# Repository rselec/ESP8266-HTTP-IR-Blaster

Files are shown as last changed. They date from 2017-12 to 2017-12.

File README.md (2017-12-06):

# IR-Gateway

Ethernet (WiFi) to IR-Code Gateway to connect normal HiFi devices to the IoT.
Firmware is a fork of https://github.com/mdhiggins/ESP8266-HTTP-IR-Blaster and modified for a special Hardware.

Versions:
0.1 - development prototype on breadboard
0.2 - flying prototype with construction parts, transmitter only, longtime-test passed
0.3 - with custom back pcb and 3D case, wip

Kurze Übersicht der wichtigen Git-Befehle/Workflow:

1. bevor gearbeitet wird, Arbeitskopie aktualisieren:
	git pull
	
2. am Projekt arbeiten, nicht zu viel auf einmal
	
3. Änderungen überprüfen:
	git status
	
4. alle Änderungen zum Index hinzufügen:
	git add *
	
5. anschließend Änderungen im Index einchecken, mit kurzer Beschreibung:
	git commit -m "Commit-Nachricht"
	
6. jetzt noch die Änderungen zu bitbucket hochladen:
	git push

Release Versionen benennen (Tagging):

1. Versionsnummer in der main.c ändern (Schema "1.0")

2. compilieren und einen commit erstellen (wie oben)

3. den commit taggen: git tag -a v1.0 -m "release of version 1.0"

4. git push und git push --tags ausführen um den Tag auf den Server zu schieben

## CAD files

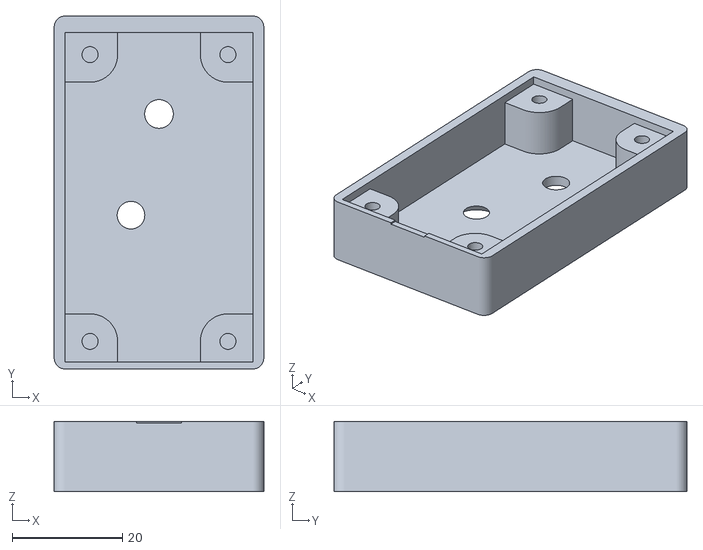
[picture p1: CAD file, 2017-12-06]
3D/STL/ir_gateway_case_03_front.stl
38.0 x 64.0 x 12.8

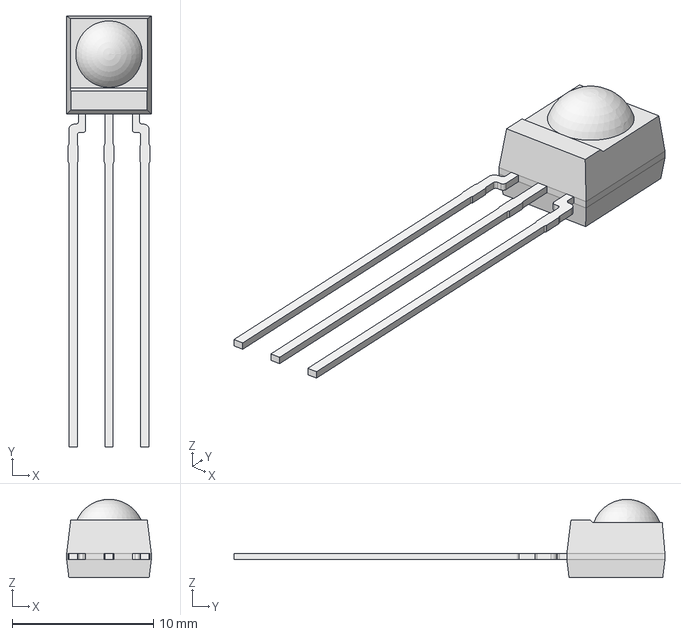
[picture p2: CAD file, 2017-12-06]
3D/TSOP483X.stp
6.00 x 30.5 x 5.55 mm
GO-100184
GO-100184.04

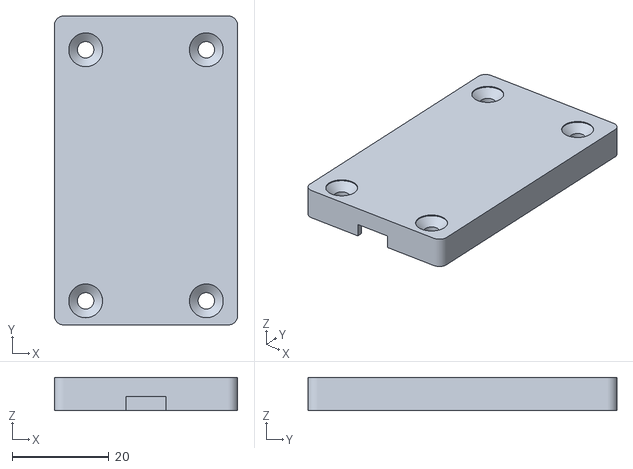
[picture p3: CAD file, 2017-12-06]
3D/STL/ir_gateway_case_03_back.stl
38.0 x 64.0 x 6.90

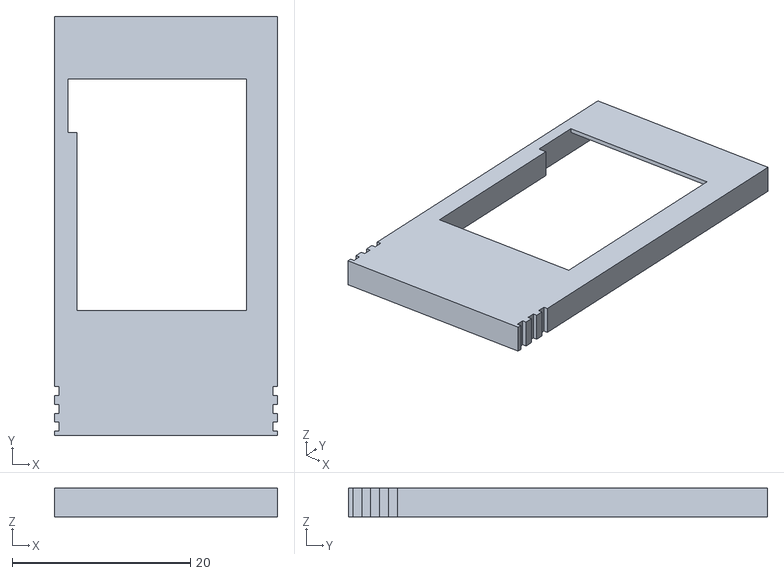
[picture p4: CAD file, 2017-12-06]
3D/STL/ir_gateway_case_03_spacer.stl
25.0 x 47.0 x 3.20

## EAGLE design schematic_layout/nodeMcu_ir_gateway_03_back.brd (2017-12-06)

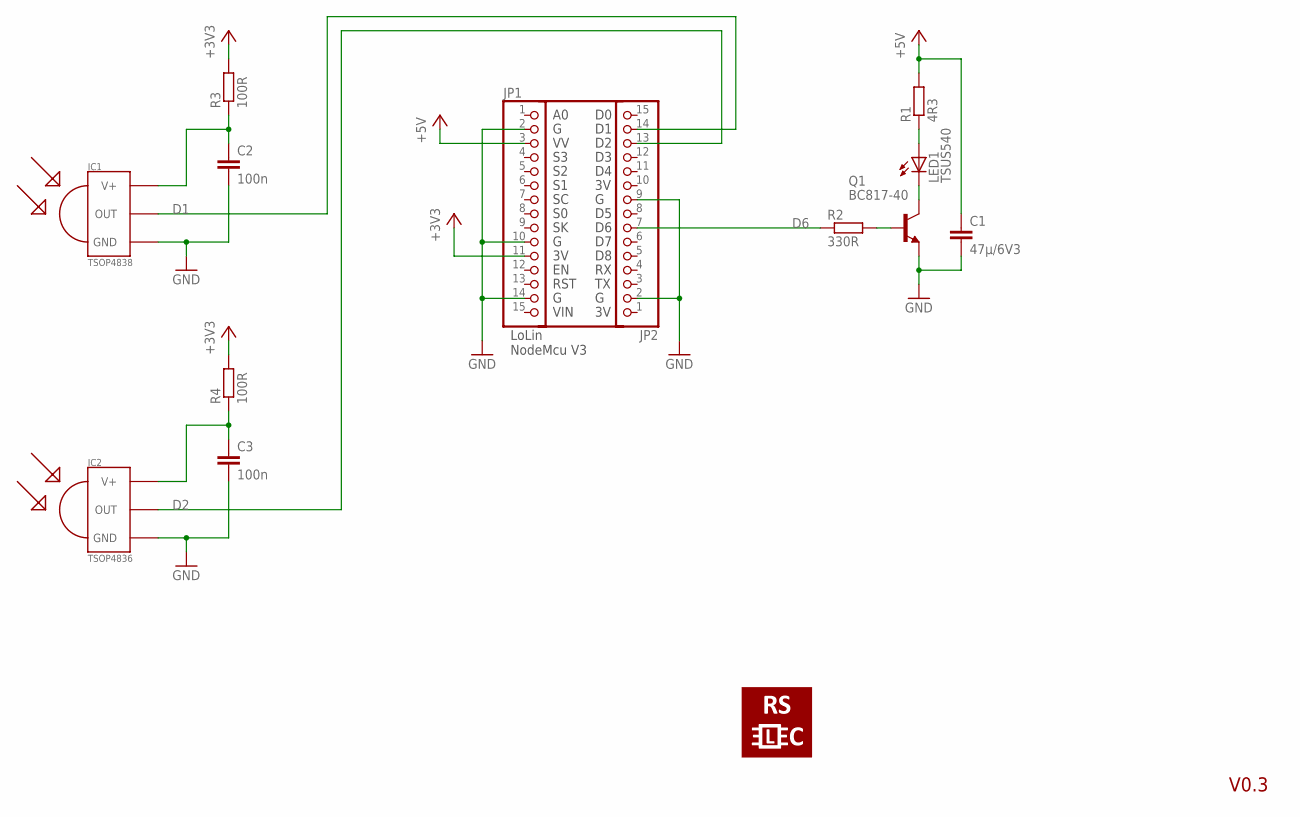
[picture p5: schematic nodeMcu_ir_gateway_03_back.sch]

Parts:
C1: 47µ/6V3; C1206
C2, C3: 100n; C0805
IC1: TSOP4838; TSOP18XX_H
IC2: TSOP4836; TSOP18XX_H
JP1, JP2: PINHD-1X15_2.54; 1X15
LED1: TSUS540; LED5MM
LOGO1: LOGO400N; LOGO_400N
Q1: BC817-40; SOT23-BEC
R1: 4R3; 0207/10
R2: 330R; R0805
R3, R4: 100R; R0805

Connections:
+3V3: JP1.11, R3.2, R4.2
+5V: C1.1, JP1.3, R1.2
D1: IC1.OUT, JP2.14
D2: IC2.OUT, JP2.13
D6: JP2.7, R2.1
GND: C1.2, C2.2, C3.2, IC1.GND, IC2.GND, JP1.2, JP1.10, JP1.14, JP2.2, JP2.9, Q1.E
unnamed: Q1.B, R2.2
unnamed: LED1.K (C), Q1.C
unnamed: LED1.A, R1.1
unnamed: C2.1, IC1.VCC (V+), R3.1
unnamed: C3.1, IC2.VCC (V+), R4.1

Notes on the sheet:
RST
VIN
LoLin NodeMcu V3
V0.3

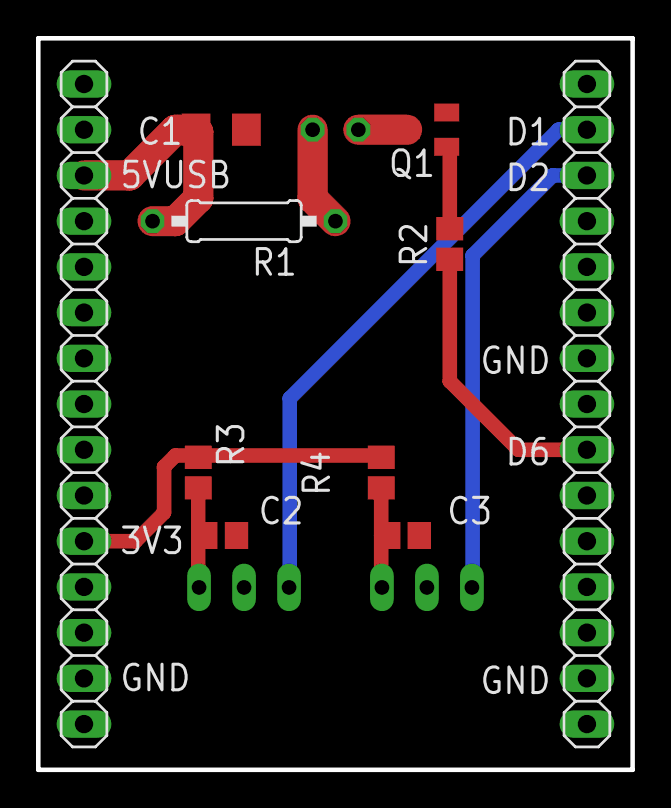
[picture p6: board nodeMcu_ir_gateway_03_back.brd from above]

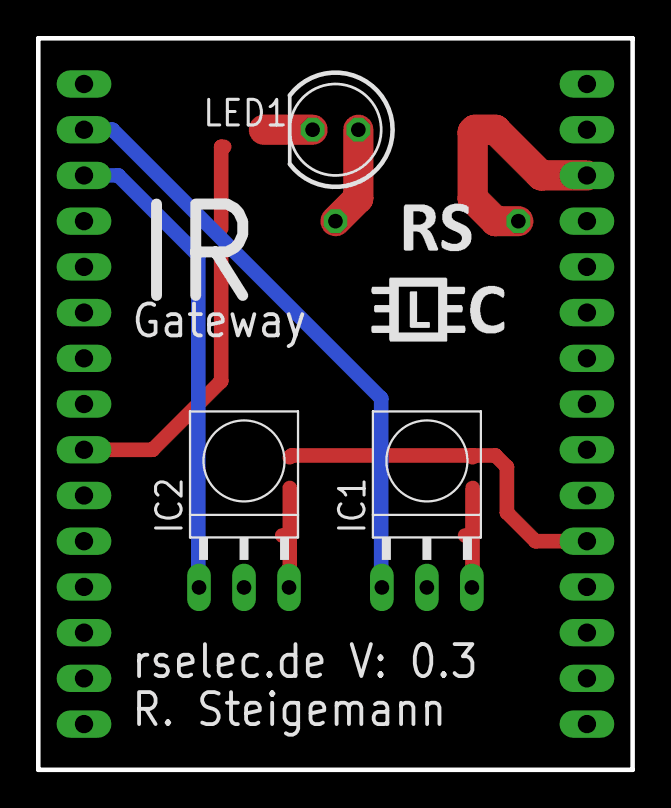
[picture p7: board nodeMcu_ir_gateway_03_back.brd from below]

Board: 2 copper layers, 33.0 x 40.6 mm, 14 parts (4 on the bottom side), 11 nets.

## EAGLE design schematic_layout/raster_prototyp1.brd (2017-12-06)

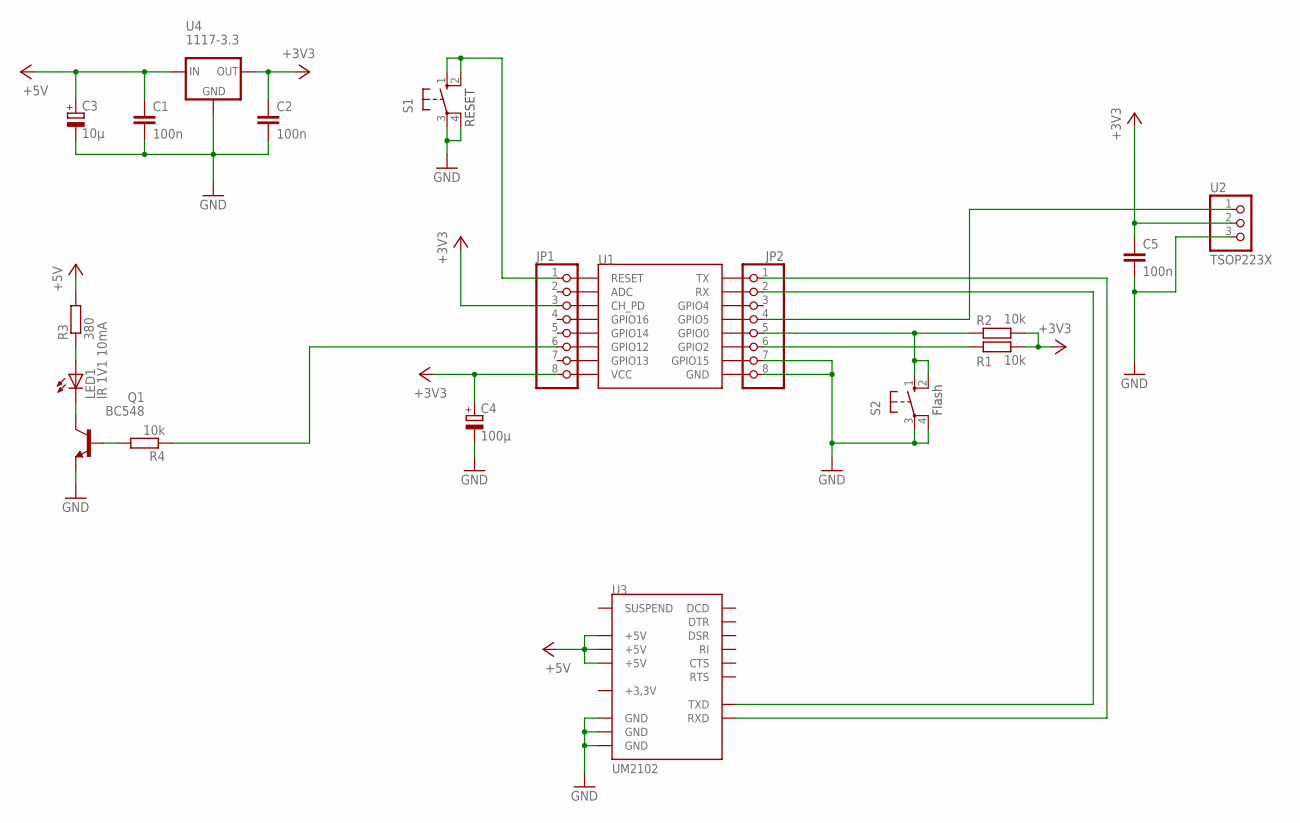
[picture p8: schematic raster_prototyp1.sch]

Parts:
C1, C2, C5: 100n; C0805
C3: 10µ; E2,5-5
C4: 100µ; E2,5-7
JP1, JP2: PINHD-1X8_2.54; 1X08
LED1: IR 1V1 10mA; LED5MM
Q1: BC548; TO92-EBC
R1, R2, R4: 10k; 0207/10
R3: 380; 0207/15
S1, S2: 10-XX; B3F-10XX
U1: ESP12SMD; ESP12-SMD
U2: TSOP223X; 1X03
U3: UM2102
U4: 1117-3.3; SOT223

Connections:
+3,3V: U3.ST2-11 (+3,3V)
+3V3: C2.1, C4.+, C5.1, JP1.3, JP1.8, R1.2, R2.2, U2.2, U4.2 (OUT)
+5V: C1.1, C3.+, R3.2, U3.ST1-3 (+5V), U3.ST2-9 (+5V), U3.ST3-7 (+5V), U4.3 (IN)
GND: C1.2, C2.2, C3.-, C4.-, C5.2, JP2.7, JP2.8, Q1.E, S1.3, S1.4 (P1), S2.3, S2.4 (P1), U2.3, U3.ST1-1 (GND), U3.ST2-7 (GND), U3.ST3-9 (GND), U4.1 (GND)
unnamed: JP2.4, U2.1
unnamed: JP2.6, R1.1
unnamed: LED1.A, R3.1
unnamed: JP1.1, S1.1 (S), S1.2 (S1)
unnamed: LED1.K (C), Q1.C
unnamed: JP2.5, R2.1, S2.1 (S), S2.2 (S1)
unnamed: Q1.B, R4.2
unnamed: JP1.6, R4.1
unnamed: JP2.1, U3.ST2-5 (RXD)
unnamed: JP2.2, U3.ST2-3 (TXD)

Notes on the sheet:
RESET
Flash

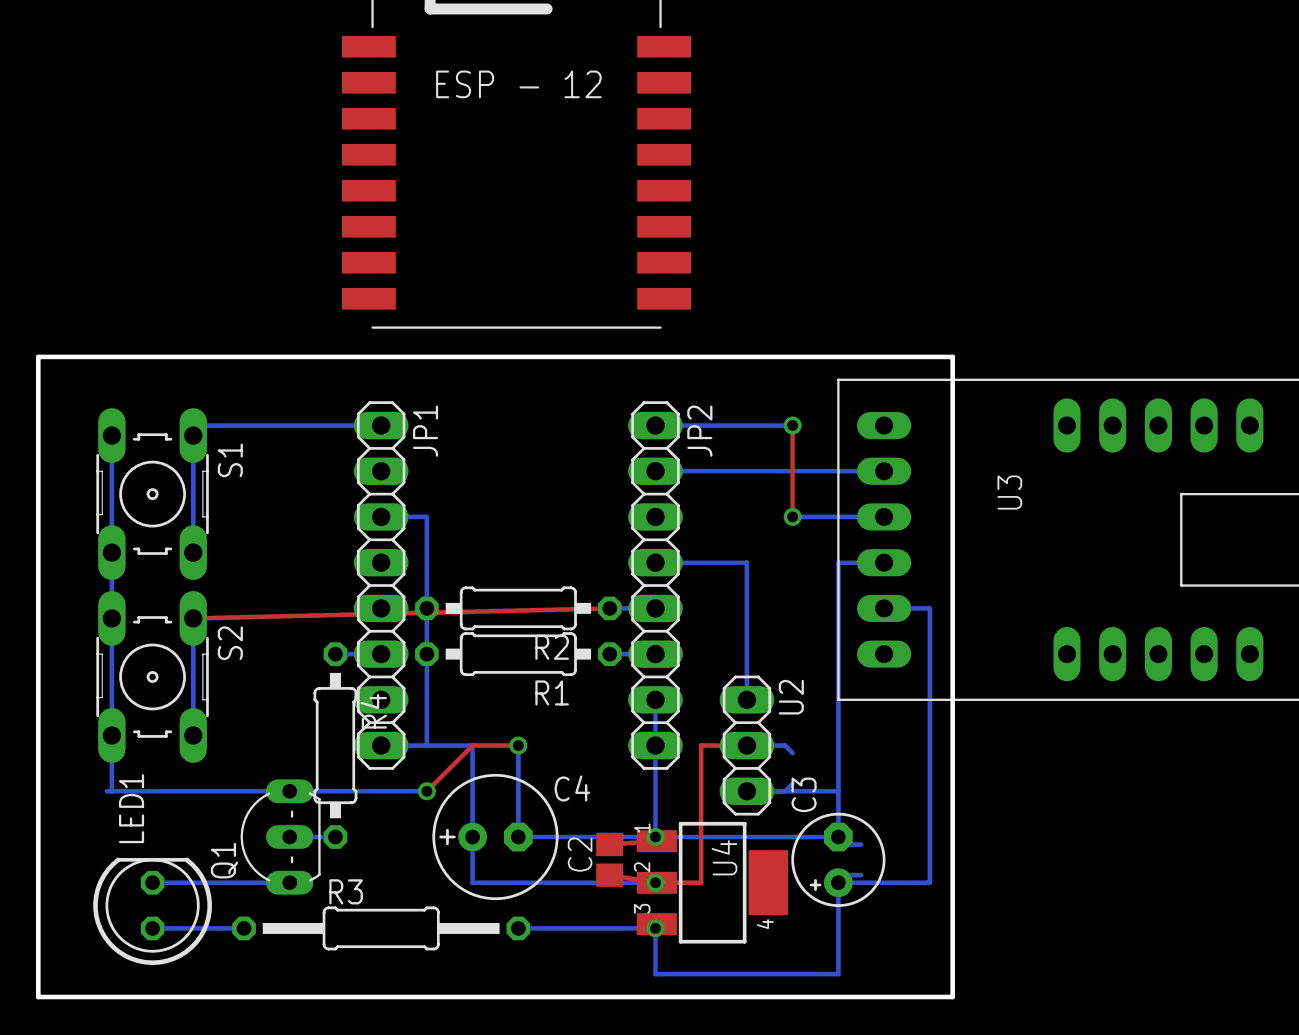
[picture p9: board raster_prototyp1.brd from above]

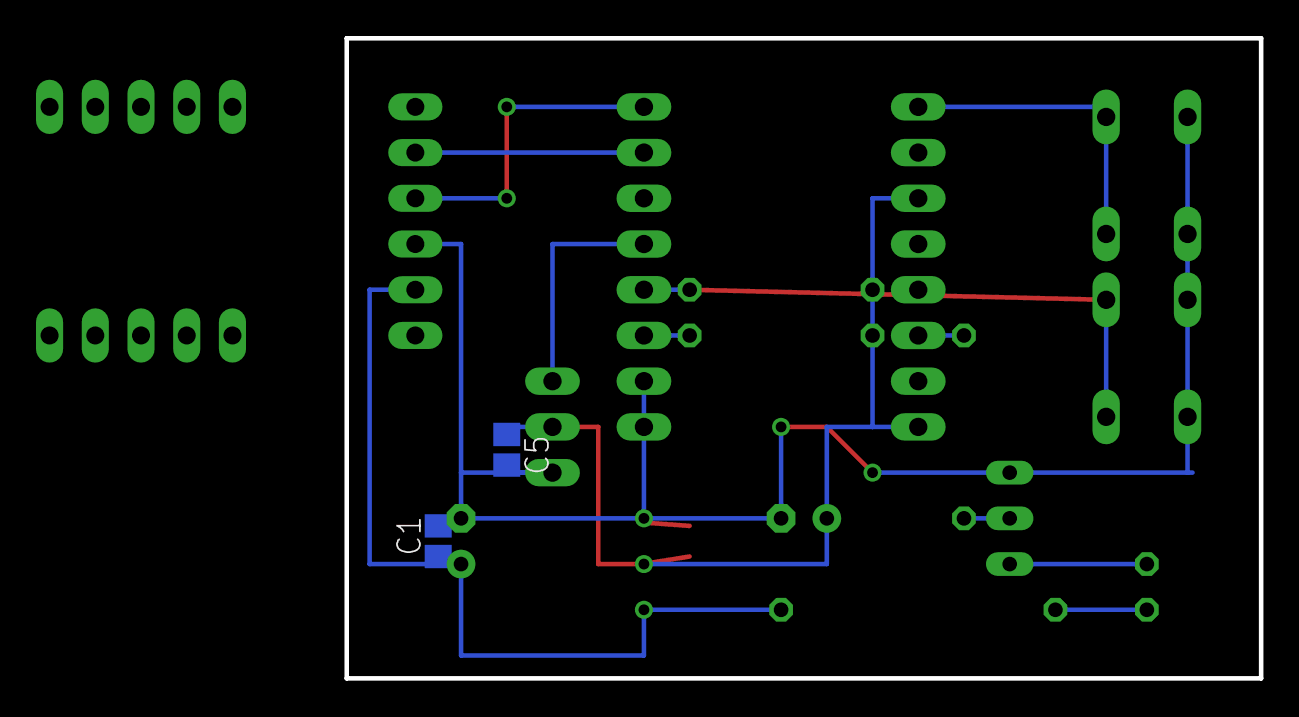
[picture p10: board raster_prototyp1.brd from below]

Board: 2 copper layers, 50.8 x 35.6 mm, 19 parts (2 on the bottom side), 13 nets.

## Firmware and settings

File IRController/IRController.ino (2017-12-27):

#include <FS.h>                                               // This needs to be first, or it all crashes and burns

#include <IRremoteESP8266.h>
#include <IRsend.h>
#include <IRrecv.h>
#include <IRutils.h>
#include <ESP8266WiFi.h>
#include <WiFiManager.h>                                      // https://github.com/tzapu/WiFiManager WiFi Configuration Magic
#include <ESP8266mDNS.h>                                      // Useful to access to ESP by hostname.local

#include <ArduinoJson.h>
#include <ESP8266WebServer.h>
#include <ESP8266HTTPClient.h>
#include <ArduinoOTA.h>
#include "sha256.h"

#include <Ticker.h>                                           // For LED status
#include <NTPClient.h>

// User settings are below here

const bool getExternalIP = false;                             // Set to false to disable querying external IP

const bool getTime = true;                                    // Set to false to disable querying for the time
const int timeOffset = +3600;                                // Timezone offset in seconds

int pinr1 = D1;                                               // Receiving pin
int pins1 = D6;                                               // Transmitting preset 1
//int pins2 = 5;                                                // Transmitting preset 2
//int pins3 = 12;                                               // Transmitting preset 3
//int pins4 = 13;                                               // Transmitting preset 4

// User settings are above here

const int configpin = 0;                                      // GPIO0 = flash key
const int ledpin = BUILTIN_LED;                               // Built in LED defined for WEMOS people
const char *wifi_config_name = "IR-Gateway Configuration";
const char serverName[] = "checkip.dyndns.org";
int port = 80;
char passcode[20] = "";
char host_name[20] = "";
char port_str[6] = "80";
char user_id[60] = "";
const char* fingerprint = "8D 83 C3 5F 0A 09 84 AE B0 64 39 23 8F 05 9E 4D 5E 08 60 06";

char static_ip[16] = "192.168.250.250";
char static_gw[16] = "192.168.250.1";
char static_sn[16] = "255.255.255.0";

DynamicJsonBuffer jsonBuffer;
JsonObject& deviceState = jsonBuffer.createObject();

ESP8266WebServer server(port);
HTTPClient http;
Ticker ticker;

bool shouldSaveConfig = false;                                // Flag for saving data
bool holdReceive = false;                                     // Flag to prevent IR receiving while transmitting

IRrecv irrecv(pinr1);
IRsend irsend1(pins1);
//IRsend irsend2(pins2);
//IRsend irsend3(pins3);
//IRsend irsend4(pins4);

const unsigned long resetfrequency = 259200000;                // 72 hours in milliseconds
const char* poolServerName = "time.nist.gov";

WiFiUDP ntpUDP;
NTPClient timeClient(ntpUDP, poolServerName, timeOffset, 3600000);

char _ip[16] = "";

unsigned long lastupdate = 0;

class Code {
  public:
    char encoding[14] = "";
    char address[20] = "";
    char command[40] = "";
    char data[40] = "";
    String raw = "";
    int bits = 0;
    char timestamp[40] = "";
    bool valid = false;
};

Code last_recv;
Code last_recv_2;
Code last_recv_3;
Code last_recv_4;
Code last_recv_5;
Code last_send;
Code last_send_2;
Code last_send_3;
Code last_send_4;
Code last_send_5;


//+=============================================================================
// Callback notifying us of the need to save config
//
void saveConfigCallback () {
  Serial.println("Should save config");
  shouldSaveConfig = true;
}


//+=============================================================================
// Reenable IR receiving
//
void resetReceive() {
  if (holdReceive) {
    Serial.println("Reenabling receiving");
    irrecv.resume();
    holdReceive = false;
  }
}


//+=============================================================================
// Valid command request using HMAC
//
bool validateHMAC(String epid, String mid, String timestamp, String signature) {
    if (!String(user_id).startsWith("amzn1.account.")) {
      Serial.println("Warning, user_id appears to be in the wrong format, security check will most likely fail. Should start with amzn1.account.***");
    }

    time_t timethen = timestamp.toInt();
    time_t timenow = timeClient.getEpochTime() - timeOffset;

    if (abs(timethen - timenow) > 30) {
      Serial.println("Failed security check, signature is too old");
      Serial.print("Server: ");
      Serial.println(timethen);
      Serial.print("Local: ");
      Serial.println(timenow);
      Serial.print("MID: ");
      Serial.println(mid);
      return false;
    }

    uint8_t *hash;
    String key = String(user_id);
    Sha256.initHmac((uint8_t*)key.c_str(), key.length()); // key, and length of key in bytes
    Sha256.print(epid);
    Sha256.print(mid);
    Sha256.print(timestamp);
    hash = Sha256.resultHmac();
    String computedSignature = bin2hex(hash, HASH_LENGTH);

    if (computedSignature != signature) {
      Serial.println("Failed security check, signatures do not match");
      Serial.print("1: ");
      Serial.println(signature);
      Serial.print("2: ");
      Serial.println(computedSignature);
      Serial.print("MID: ");
      Serial.println(mid);
      return false;
    }

    Serial.println("Passed security check");
    Serial.print("MID: ");
    Serial.println(mid);
    return true;
}


//+=============================================================================
// Get User_ID from Amazon Token (memory intensive and causes crashing)
//
String getUserID(String token)
{
  http.setTimeout(5000);
  String url = "https://api.amazon.com/user/profile?access_token=";
  String uid = "";
  http.begin(url + token, fingerprint);
  int httpCode = http.GET();
  String payload = http.getString();
  Serial.println(url + token);
  Serial.println(httpCode);
  Serial.println(payload);
  if (httpCode > 0 && httpCode == HTTP_CODE_OK) {
    DynamicJsonBuffer jsonBuffer;
    JsonObject& json = jsonBuffer.parseObject(payload);
    uid = json["user_id"].as<String>();
  } else {
    Serial.println("Error retrieving user_id");
    payload = "";
  }
  http.end();
  return uid;
}


//+=============================================================================
// Toggle state
//
void tick()
{
  int state = digitalRead(ledpin);  // get the current state of GPIO1 pin
  digitalWrite(ledpin, !state);     // set pin to the opposite state
}


//+=============================================================================
// Get External IP Address
//
String externalIP()
{
  if (!getExternalIP) {
    return "0.0.0.0"; // User doesn't want the external IP
  }

  if (strlen(_ip) > 0) {
    if (millis() - lastupdate > resetfrequency || lastupdate > millis()) {
      Serial.println("Reseting cached external IP address");
      strncpy(_ip, "", 16); // Reset the cached external IP every 72 hours
    } else {
      return String(_ip); // Return the cached external IP
    }
  }
  unsigned long start = millis();
  http.setTimeout(5000);
  http.begin(serverName, 8245);
  int httpCode = http.GET();

  if (httpCode > 0 && httpCode == HTTP_CODE_OK) {
    String payload = http.getString();
    int pos_start = payload.indexOf("IP Address") + 12; // add 10 for "IP Address" and 2 for ":" + "space"
    int pos_end = payload.indexOf("</body>", pos_start); // add nothing
    strncpy(_ip, payload.substring(pos_start, pos_end).c_str(), 16);
    Serial.print(F("External IP: "));
    Serial.println(_ip);
  } else {
    Serial.println("Error retrieving external IP");
  }

  http.end();
  Serial.print("External IP address request took ");
  Serial.print(millis() - start);
  Serial.println(" ms");

  return _ip;
}


//+=============================================================================
// Turn off the Led after timeout
//
void disableLed()
{
  Serial.println("Turning off the LED to save power.");
  digitalWrite(ledpin, HIGH);                           // Shut down the LED
  ticker.detach();                                      // Stopping the ticker
}


//+=============================================================================
// Gets called when WiFiManager enters configuration mode
//
void configModeCallback (WiFiManager *myWiFiManager) {
  Serial.println("Entered config mode");
  Serial.println(WiFi.softAPIP());
  //if you used auto generated SSID, print it
  Serial.println(myWiFiManager->getConfigPortalSSID());
  //entered config mode, make led toggle faster
  ticker.attach(0.2, tick);
}

//+=============================================================================
// Gets called when device loses connection to the accesspoint
//
void lostWifiCallback (const WiFiEventStationModeDisconnected& evt) {
  Serial.println("Lost Wifi");
  // reset and try again, or maybe put it to deep sleep
  ESP.reset();
  delay(1000);
}

//+=============================================================================
// First setup of the Wifi.
// If return true, the Wifi is well connected.
// Should not return false if Wifi cannot be connected, it will loop
//
bool setupWifi(bool resetConf) {
  // set led pin as output
  pinMode(ledpin, OUTPUT);
  // start ticker with 0.5 because we start in AP mode and try to connect
  ticker.attach(0.6, tick);

  // WiFiManager
  // Local intialization. Once its business is done, there is no need to keep it around
  WiFiManager wifiManager;
  // reset settings - for testing
  if (resetConf)
    wifiManager.resetSettings();

  // set callback that gets called when connecting to previous WiFi fails, and enters Access Point mode
  wifiManager.setAPCallback(configModeCallback);
  // set config save notify callback
  wifiManager.setSaveConfigCallback(saveConfigCallback);

  // Reset device if on config portal for greater than 10 minutes
  wifiManager.setConfigPortalTimeout(600);

  if (SPIFFS.begin()) {
    Serial.println("mounted file system");
    if (SPIFFS.exists("/config.json")) {
      //file exists, reading and loading
      Serial.println("reading config file");
      File configFile = SPIFFS.open("/config.json", "r");
      if (configFile) {
        Serial.println("opened config file");
        size_t size = configFile.size();
        // Allocate a buffer to store contents of the file.
        std::unique_ptr<char[]> buf(new char[size]);

        configFile.readBytes(buf.get(), size);
        DynamicJsonBuffer jsonBuffer;
        JsonObject& json = jsonBuffer.parseObject(buf.get());
        json.printTo(Serial);
        if (json.success()) {
          Serial.println("\nparsed json");

          if (json.containsKey("hostname")) strncpy(host_name, json["hostname"], 20);
          if (json.containsKey("passcode")) strncpy(passcode, json["passcode"], 20);
          if (json.containsKey("user_id")) strncpy(user_id, json["user_id"], 60);
          if (json.containsKey("port_str")) {
            strncpy(port_str, json["port_str"], 6);
            port = atoi(json["port_str"]);
          }
          if (json.containsKey("ip")) strncpy(static_ip, json["ip"], 16);
          if (json.containsKey("gw")) strncpy(static_gw, json["gw"], 16);
          if (json.containsKey("sn")) strncpy(static_sn, json["sn"], 16);
        } else {
          Serial.println("failed to load json config");
        }
      }
    }
  } else {
    Serial.println("failed to mount FS");
  }


  WiFi.hostname().toCharArray(host_name, 20);
  WiFiManagerParameter custom_hostname("hostname", "Choose a hostname to this IR Controller", host_name, 20);
  wifiManager.addParameter(&custom_hostname);
  WiFiManagerParameter custom_passcode("passcode", "Choose a passcode", passcode, 20);
  wifiManager.addParameter(&custom_passcode);
  WiFiManagerParameter custom_port("port_str", "Choose a port", port_str, 6);
  wifiManager.addParameter(&custom_port);
  WiFiManagerParameter custom_userid("user_id", "Enter your Amazon user_id", user_id, 60);
  wifiManager.addParameter(&custom_userid);

  IPAddress sip, sgw, ssn;
  sip.fromString(static_ip);
  sgw.fromString(static_gw);
  ssn.fromString(static_sn);
  Serial.println("Using Static IP");
  wifiManager.setSTAStaticIPConfig(sip, sgw, ssn);

  // fetches ssid and pass and tries to connect
  // if it does not connect it starts an access point with the specified name
  // and goes into a blocking loop awaiting configuration
  if (!wifiManager.autoConnect(wifi_config_name)) {
    Serial.println("failed to connect and hit timeout");
    // reset and try again, or maybe put it to deep sleep
    ESP.reset();
    delay(1000);
  }

  // if you get here you have connected to the WiFi
  strncpy(host_name, custom_hostname.getValue(), 20);
  strncpy(passcode, custom_passcode.getValue(), 20);
  strncpy(port_str, custom_port.getValue(), 6);
  strncpy(user_id, custom_userid.getValue(), 60);
  port = atoi(port_str);

  if (port != 80) {
    Serial.println("Default port changed");
    server = ESP8266WebServer(port);
  }

  // Reset device if lost wifi Connection
  WiFi.onStationModeDisconnected(&lostWifiCallback);

  Serial.println("WiFi connected! User chose hostname '" + String(host_name) + String("' passcode '") + String(passcode) + "' and port '" + String(port_str) + "'");

  // save the custom parameters to FS
  if (shouldSaveConfig) {
    Serial.println(" config...");
    DynamicJsonBuffer jsonBuffer;
    JsonObject& json = jsonBuffer.createObject();
    json["hostname"] = host_name;
    json["passcode"] = passcode;
    json["port_str"] = port_str;
    json["user_id"] = user_id;
    json["ip"] = WiFi.localIP().toString();
    json["gw"] = WiFi.gatewayIP().toString();
    json["sn"] = WiFi.subnetMask().toString();

    File configFile = SPIFFS.open("/config.json", "w");
    if (!configFile) {
      Serial.println("failed to open config file for writing");
    }

    json.printTo(Serial);
    Serial.println("");
    json.printTo(configFile);
    configFile.close();
    jsonBuffer.clear();
  }
  ticker.detach();

  // keep LED on
  digitalWrite(ledpin, LOW);
  return true;
}
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
void loop() {
  server.handleClient();
  ArduinoOTA.handle();
  decode_results  results;                                        // Somewhere to store the results
  if (getTime || strlen(user_id) != 0) timeClient.update();                               // Update the time

  if (irrecv.decode(&results) && !holdReceive) {                  // Grab an IR code
    if (results.decode_type != UNKNOWN) {                         // Display only known codes
    Serial.println("Signal received:");
    fullCode(&results);                                           // Print the singleline value
    dumpCode(&results);                                           // Output the results as source code
    copyCode(last_recv_4, last_recv_5);                           // Pass
    copyCode(last_recv_3, last_recv_4);                           // Pass
    copyCode(last_recv_2, last_recv_3);                           // Pass
    copyCode(last_recv, last_recv_2);                             // Pass
    cvrtCode(last_recv, &results);                                // Store the results
    strncpy(last_recv.timestamp, String(timeClient.getFormattedTime()).c_str(), 40);  // Set the new update time
    last_recv.valid = true;
    Serial.println("");                                           // Blank line between entries    
    digitalWrite(ledpin, LOW);                                    // Turn on the LED for 0.5 seconds
    ticker.attach(0.5, disableLed);
	}
	irrecv.resume();                                                // Prepare for the next value
  }
  
  if(digitalRead(configpin) == LOW)                               // Reset by pressing Flash key to enable reconfiguration
  {
    ESP.reset();
  }  
  
  delay(200);
}

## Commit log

2017-12-06 added project stuff
    [IR-codes.xlsx, TSOP483X.stp, ir_gateway_case_03_back.stl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]
2017-12-06 added reset at config switch press
    [IRController.ino]
2017-12-27 Fixed issues around panasonic address, works but mess with command (without addres) data (addres+command) and seperate address field isn't nice yet! Also fixed bug with stringcompare.
    [IRController.ino]
